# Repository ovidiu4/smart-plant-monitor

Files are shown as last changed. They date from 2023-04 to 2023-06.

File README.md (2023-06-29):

# ESP32 Powered Smart Plant Monitor

**Hello. This project is ongoing, therefore changes will be frequent.**

**Please feel free to use any part of my work for your personal projects only.**

**For commercial use please contact me!**

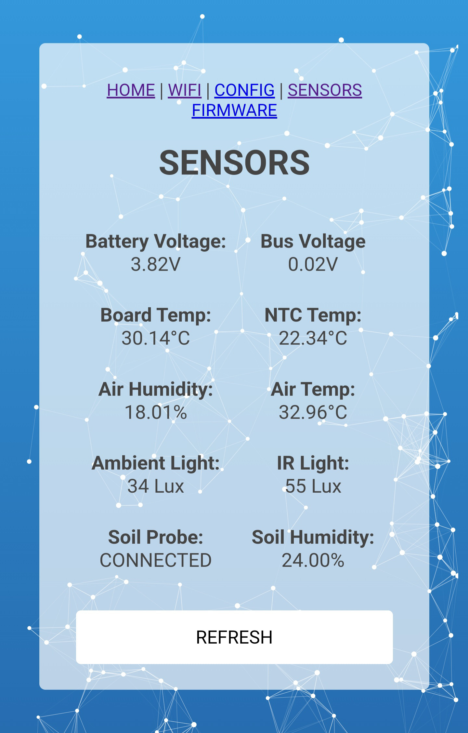
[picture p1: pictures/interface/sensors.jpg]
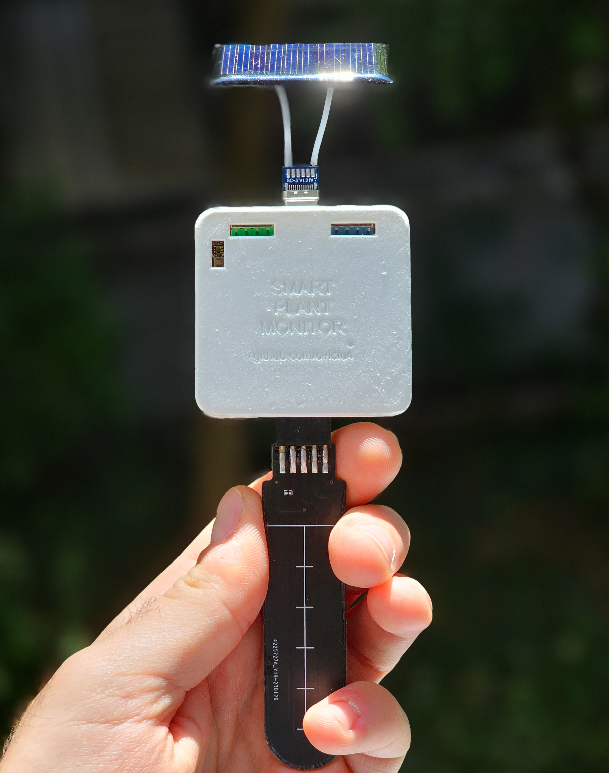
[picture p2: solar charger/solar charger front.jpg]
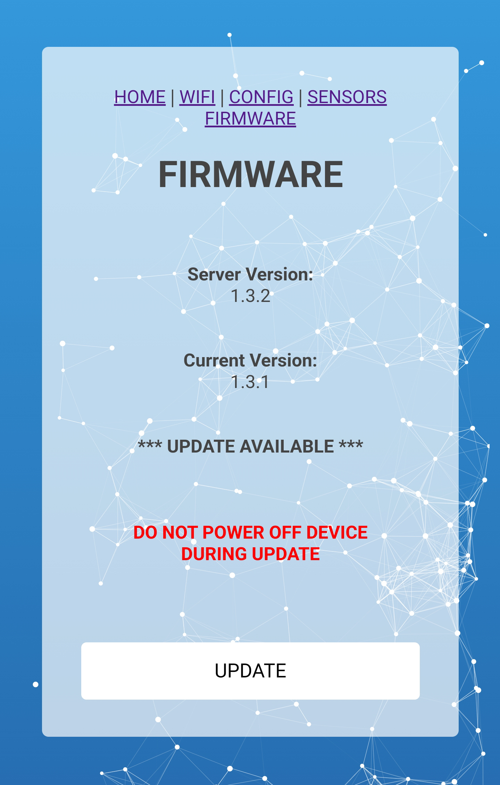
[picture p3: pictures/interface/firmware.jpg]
    

Overall features:
- Low power and small size (45x45x10mm)
- Rechargeable and programable with Arduino
- By adding a USB port to a small solar panel you've created a simple add-on 
- Can communicate via WIFI or Bluetooth
- One device can stay plugged in all the time (act as hub) while the others send updates to it (low power mode)

Back of the main board. Features:
- ESP32-S3 supports capacitance measuring directly, through the touchpad circuitry
- TP4056 charging + protection circuit
- USB C with 5.1K resistors added
- 3.3V LDO for powering everything
- Circuitry for a 1.54" E-Paper display (goes on the back)
- AHT20 IC for local air humidity and temperature measurement
- Card edge connector for easy and cheap "soil probe" PCB swap
- 2 GPIO buttons (one connected to GPIO0) and 1 status LED

Front of the main board. Features:
- Battery on-off switch
- I2C header for possible module addition
- E-Paper display
- Slim LiPo battery goes under the display. Could fit up to 4x40x30mm (usually 450-500mAh)

Soil probe. Features:
- No components and connectors added, just the bare PCB
- Cheap and easy to replace when they eventually breakdown in the soil
- Solder pads avaialble if you'd like to add a 0603 component (LED or Thermistor for soil surface temperature). Connected to GPIO through a 2K resistor
- Can be in any size and shape you'd like as long as the top matches the conector (calibration and adjustments are done in software)

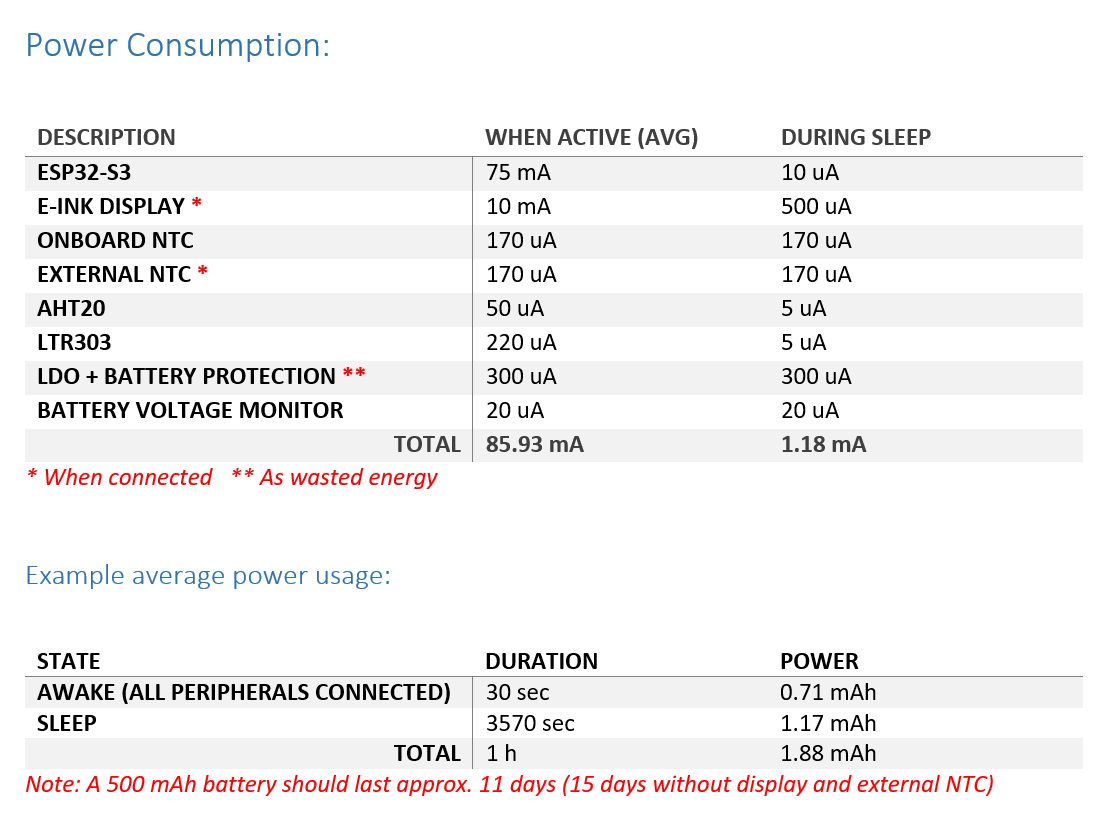
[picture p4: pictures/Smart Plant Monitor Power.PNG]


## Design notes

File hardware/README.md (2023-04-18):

If you'd like to order your own, please feel free to use the fabrication files attached here!

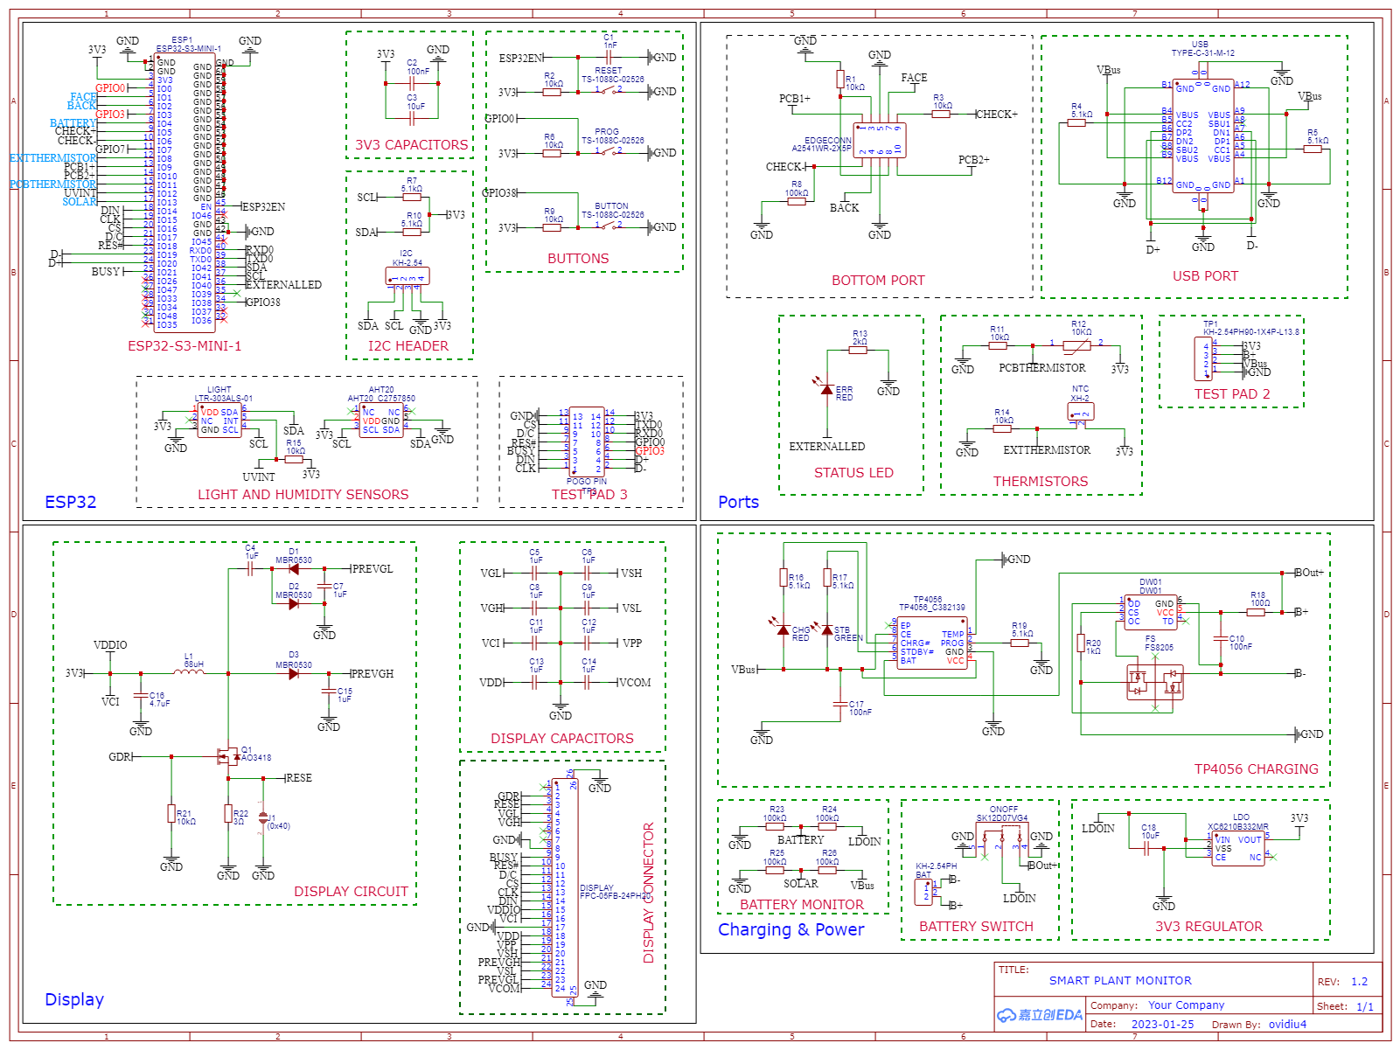
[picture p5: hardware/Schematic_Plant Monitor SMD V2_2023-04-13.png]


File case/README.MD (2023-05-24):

**STL Files for a case that perfectly fits the Smart Plant Monitor**

  


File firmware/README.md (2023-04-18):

This folder is used for the automatic updates of the board.
There is no need to download anything from here

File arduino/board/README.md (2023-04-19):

**In order to program the board yourself via Arduino IDE you need to create a custom board**

1. Add the contens of boards.txt to your boards file on your computer. It is typically located at:
   "C:\Users\\\*USER*\AppData\Local\Arduino15\packages\esp32\hardware\esp32\2.0.7\boards.txt"

2. Copy the entire folder "ovidiu4_esp32s3" to the variants folder on your computer. It is typically located at:
   "C:\Users\\\*USER*\AppData\Local\Arduino15\packages\esp32\hardware\esp32\2.0.7\variants\"
   
3. Restart Arduino and select the custom board "Ovidiu4 Smart Plant Monitor ESP32-S3"

4. Adjust the following settings:

   a. USB Mode: Hardware CDC and JTAG

   b. CPU Frequency: 80MHz

   c. Partition Scheme: Default 4MB with SPIFFS

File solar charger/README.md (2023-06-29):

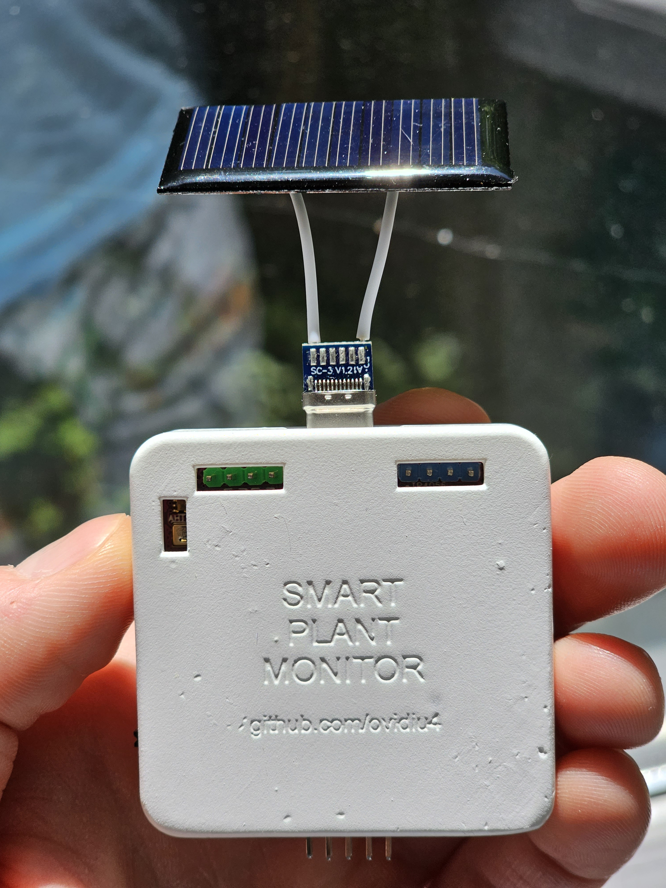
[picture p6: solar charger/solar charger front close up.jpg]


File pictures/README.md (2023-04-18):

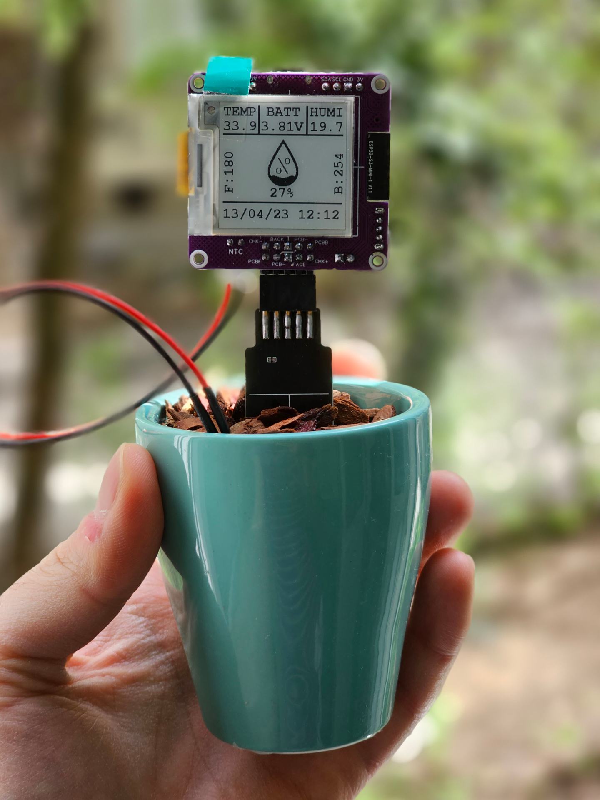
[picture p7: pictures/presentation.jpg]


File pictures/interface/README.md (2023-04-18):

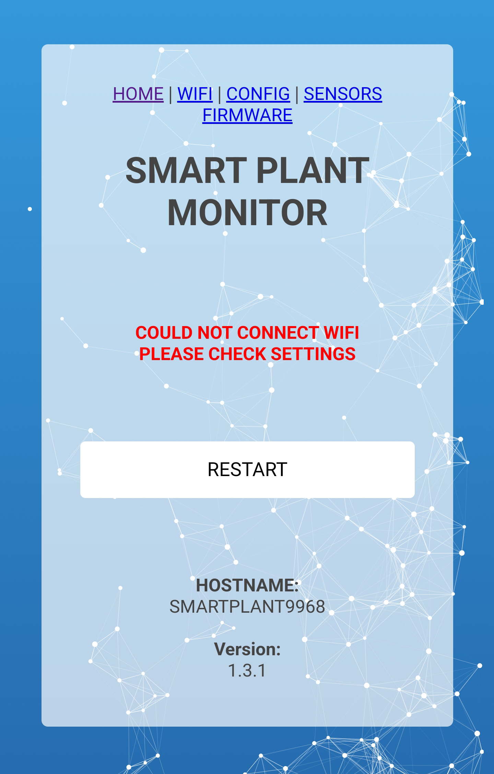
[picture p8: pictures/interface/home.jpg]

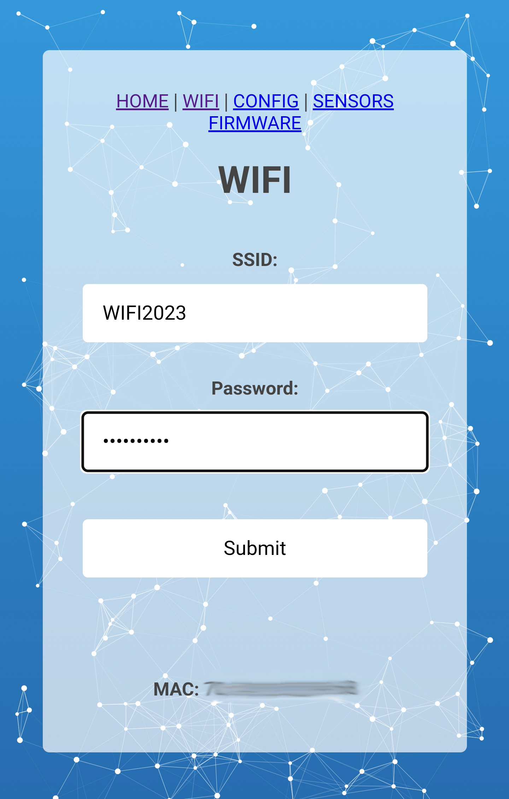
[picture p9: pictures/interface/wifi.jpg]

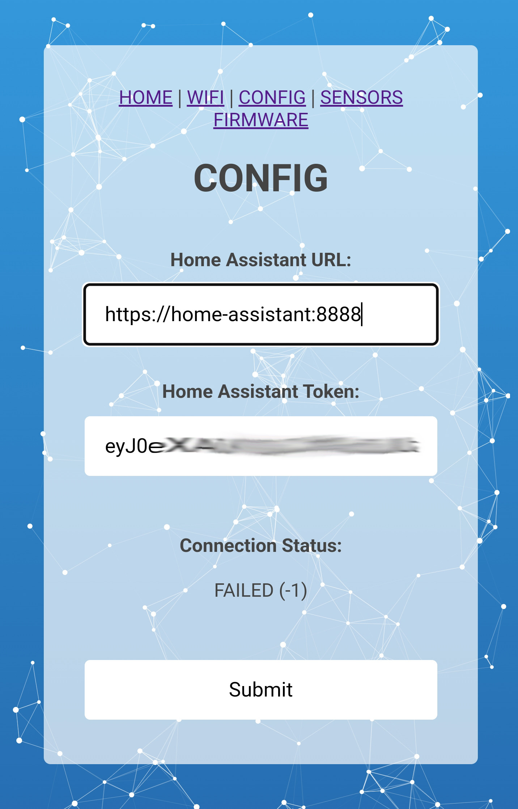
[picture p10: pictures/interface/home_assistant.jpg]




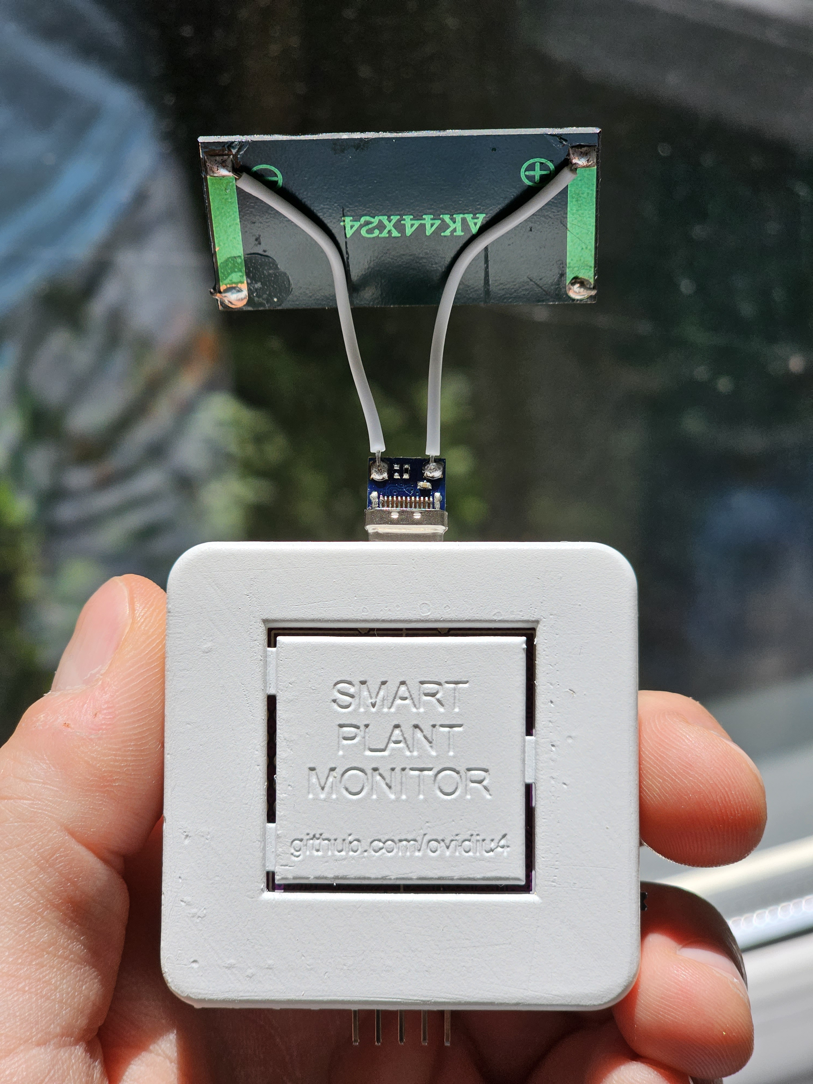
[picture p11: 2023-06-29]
solar charger/solar charger back close up.jpg

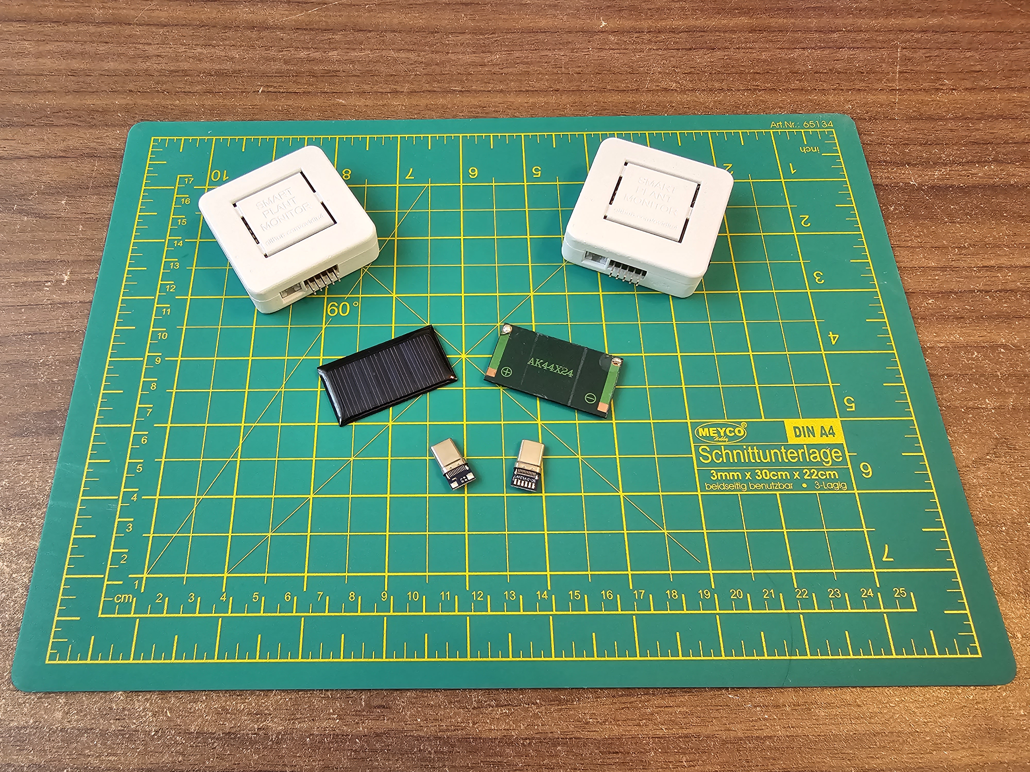
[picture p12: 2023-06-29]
solar charger/mini solar panel and usb connector.jpg

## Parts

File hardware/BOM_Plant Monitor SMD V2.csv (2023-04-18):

ID | Name | Designator | Footprint | Quantity | Manufacturer Part | Manufacturer | Supplier | Supplier Part | Price
1 | AHT20_C2757850 | AHT20 | SENSOR-SMD_L3.0-W3.0-P1.00-BR | 1 | AHT20 | 广州奥松 | LCSC | C2757850 | 0.117
2 | 1nF | C1 | C0603 | 1 | CL10B102KB8NNNC | SAMSUNG(三星) | LCSC | C1588 | 0.001
3 | 100nF | C2,C10,C17 | C0603 | 3 | CC0603KRX7R9BB104 | YAGEO(国巨) | LCSC | C14663
4 | 10uF | C3,C18 | C0603 | 2 | CL10A106KP8NNNC | SAMSUNG(三星) | LCSC | C19702 | 0.001
5 | 1uF | C4,C5,C6,C7,C8,C9,C11,C12,C13,C14,C15 | C0603 | 11 | CL10A105KB8NNNC | SAMSUNG(三星) | LCSC | C15849 | 0.001
6 | 4.7uF | C16 | C0603 | 1 | CL10A475KO8NNNC | SAMSUNG(三星) | LCSC | C19666 | 0.002
7 | RED | CHG,ERR | LED0603-R-RD | 2 | KT-0603R | KENTO | LCSC | C2286
8 | MBR0530 | D1,D2,D3 | SOD-123_L2.8-W1.8-LS3.7-RD | 3 | MBR0530 | CJ(江苏长电/长晶) | LCSC | C77336 | 0.005
9 | FPC-05FB-24PH20 | DISPLAY | FPC-SMD_24P-P0.50_FPC-05FB-24PH20 | 1 | FPC-05FB-24PH20 | XUNPU(讯普) | LCSC | C2856831 | 0.023
10 | DW01 | DW01 | SOT-23-6_L2.9-W1.6-P0.95-LS2.8-BR | 1 | DW01 | Hottech(合科泰) | LCSC | C181096 | 0.006
11 | ESP32-S3-MINI-1 | ESP1 | BULETM-SMD_ESP32-S3-MINI-1-N8 | 1 | ESP32-S3-MINI-1 | null | LCSC | C9900015247
12 | FS8205 | FS | SOT-23-6_L2.9-W1.6-P0.95-LS2.8-BR | 1 | FS8205 | FORTUNE(富晶) | LCSC | C32254 | 0.031
13 | (0x40) | J1 | JUMPER2-0603_NC | 1 | ?
14 | 68uH | L1 | L1210 | 1 | CMI322513J680MT | FH(风华) | LCSC | C401470 | 0.015
15 | XC6210B332MR | LDO | TSOT-23-5_L2.9-W1.6-P0.95-LS2.8-BR | 1 | XC6210B332MR | TOREX(特瑞仕) | LCSC | C424705 | 0.056
16 | LTR-303ALS-01 | LIGHT | SOT-363_L2.0-W1.3-P0.65-LS2.1-BL | 1 | LTR-303ALS-01 | LITEON(光宝) | LCSC | C364577 | 0.063
17 | AO3418 | Q1 | SOT-23-3_L2.9-W1.3-P1.90-LS2.4-BR | 1 | AO3418 | AOS | LCSC | C21713 | 0.015
18 | 10kΩ | R1,R2,R3,R6,R9,R11,R14,R15,R21 | R0603 | 9 | 0603WAF1002T5E | UNI-ROYAL(厚声) | LCSC | C25804
19 | 5.1kΩ | R4,R5,R7,R10,R16,R17,R19 | R0603 | 7 | 0603WAF5101T5E | UNI-ROYAL(厚声) | LCSC | C23186
20 | 100kΩ | R8,R23,R24,R25,R26 | R0603 | 5 | 0603WAF1003T5E | UNI-ROYAL(厚声) | LCSC | C25803
21 | 10KΩ | R12 | R0603 | 1 | NTCS0603E3103FLT | VISHAY(威世) | LCSC | C142556 | 0.112
22 | 2kΩ | R13 | R0603 | 1 | 0603WAF2001T5E | UNI-ROYAL(厚声) | LCSC | C22975
23 | 100Ω | R18 | R0603 | 1 | 0603WAF1000T5E | UNI-ROYAL(厚声) | LCSC | C22775
24 | 1kΩ | R20 | R0603 | 1 | 0603WAF1001T5E | UNI-ROYAL(厚声) | LCSC | C21190
25 | 3Ω | R22 | R0603 | 1 | 0603WAF300KT5E | UNI-ROYAL(厚声) | LCSC | C23157
26 | GREEN | STB | LED0603-R-RD | 1 | 19-217/GHC-YR1S2/3T | EVERLIGHT | LCSC | C72043 | 0.004
27 | TP4056_C382139 | TP4056 | ESOP-8_L4.9-W3.9-P1.27-LS6.0-BL-EP | 1 | TP4056 | TPOWER | LCSC | C382139 | 0.019
28 | TYPE-C-31-M-12 | USB | USB-C_SMD-TYPE-C-31-M-12 | 1 | TYPE-C-31-M-12 | Rectangular Connectors - Contacts | LCSC | C165948 | 0.035

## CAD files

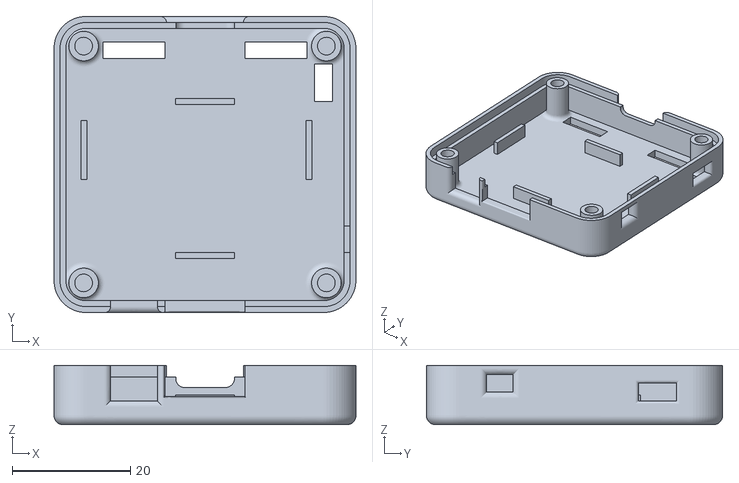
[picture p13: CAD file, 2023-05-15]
case/Case Bottom.stl
51.0 x 50.0 x 10.00

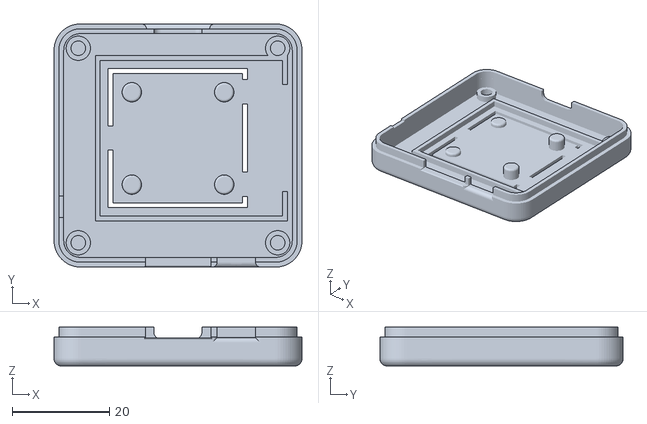
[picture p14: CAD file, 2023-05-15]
case/Case Top.stl
51.0 x 50.0 x 8.00

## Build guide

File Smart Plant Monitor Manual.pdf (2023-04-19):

# Smart Plant Monitor

Based on the ESP32-S3-MINI-1

## Board Overview:

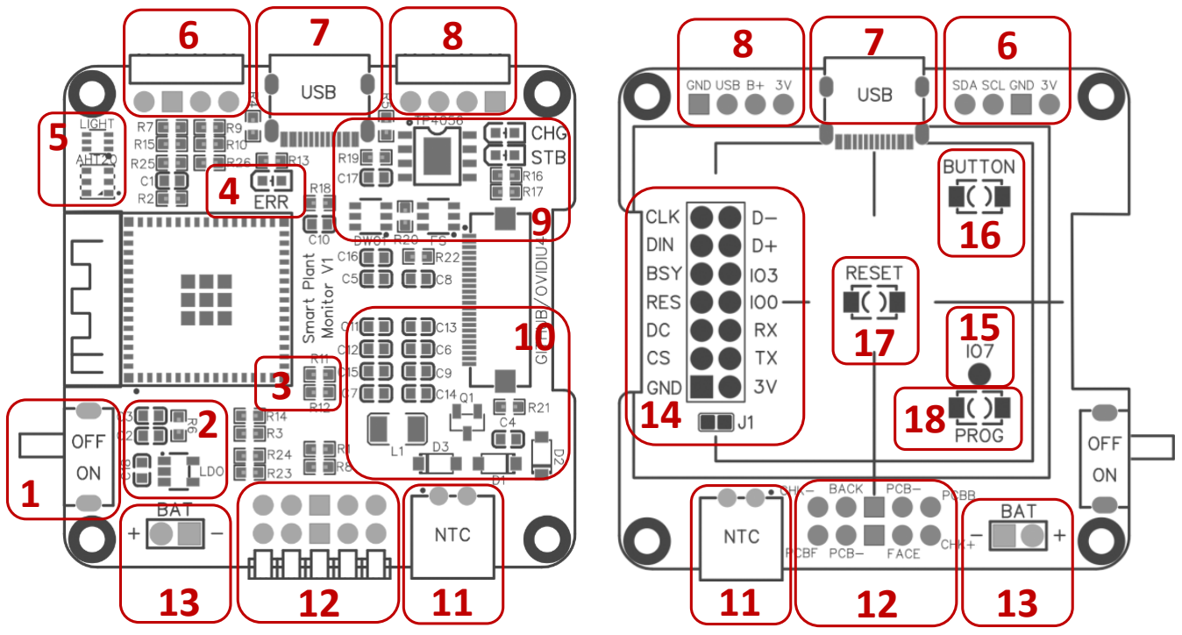
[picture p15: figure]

1. ON/OFF Switch: Connects the LDO (2) to the battery charge/protection (9) circuit.
2. 3.3V LDO: Powers all components and sensors
3. Board Thermistor: This thermistor is used to measure the board temperature. If a battery is installed over it, it can detect overheating
4. “ERR” LED: This LED is used as a status LED to signal different states of the device (Booting, firmware updating, etc.)
5. Air and Light sensors: Will measure air humidity and temperature, ambient and IR light. The light sensor can wake up the processor when certain threshold in Lux is met (Detect day time, etc.)
6. I2C Header: Can be used to connect external devices (Relays, etc.)
7. USB Port: Can be used to charge the battery and to program the ESP32-S3
8. Voltage test pins: Can be used to measure/calibrate the different voltage levels of the board. Can also be used to inject voltage (Connect the USB pin to a 6V solar panel, connect the B+ pin to an external Li-Po battery instead of the internal one (13), etc.
9. Li-Po Charge and protection circuit: Offers various protection features:
a. 400 mA max charging / discharging current
b. Short circuit protection

c. Over charge protection
d. Over discharge protection
10. E-Ink display power circuit
11. NTC connector: Used to attach an external 10K NTC thermistor (Can be used to monitor soil temperature, etc.)
12. Soil probe connector
13. Internal Li-Po battery connector
14. Test pads: Wires can be soldered directly to the test pads and they can be reconfigured in software for your personal use
15. IO7: Connected directly to GPIO7 of the ESP32-S3. Please add a current limiting resistor (max 40mA) to avoid burning of the processor
16. Button: Hold down for 5 sec at startup to change boot mode to config mode. Hold for 10 sec to factory reset the device
17. Reset: Can be shorted to reset the device (Pulls the EN pin low)
18. Prog: Hold down at startup to enter programming mode. Used when programming via USB using Arduino IDE or other software

## Board Pinout:

Please see below the default pinout for the device with the corresponding GPIO connections.

For more details please check the schematic

Smart Plant Monitor Pin | ESP32-S3-MINI-1 Pin | Remarks
“Prog” button (18) | GPIO0 | Input. Pulled low via 10K resistor
“Face” (12) | GPIO1 | Input. No resistor
“Back” (12) | GPIO2 | Input. No resistor
“IO3 “ (14) | GPIO3 | No resistor
Battery Voltage | GPIO4 | Input. R23-R24 voltage divider
“CHK+” (12) | GPIO5 | Output. 10K resistor in series
“CHK-” (12) | GPIO6 | Input. Pulled low via 100K resistor
“IO7 “ (15) | GPIO7 | No resistor
External Thermistor (11) | GPIO8 | Input. Pulled low via 10K resistor
“PCBF” (12) | GPIO9 | No resistor
“PCBB” (12) | GPIO10 | No resistor
“PCB-“ (12) | GND | 10K resistor in series
PCB Thermistor (3) | GPIO11 | Input. Pulled low via 10K resistor
Light Interrupt | GPIO12 | Input. Pulled high via 10K resistor
VBUS Voltage | GPIO13 | Input. R25-R26 voltage divider
“DIN” (14) | GPIO14 | SPI MOSI
“CLK” (14) | GPIO15 | SPI CLK
“CS” (14) | GPIO16 | SPI CS
“DC” (14) | GPIO17 | SPI D/C
“RES” (14) | GPIO18 | SPI RES
USB D- | GPIO19
USB D+ | GPIO20
“BSY” (14) | GPIO21 | SPI Busy
“BUTTON” (16) | GPIO38 | Input. Pulled low via 10K resistor
“ERR” LED (4) | GPIO40
SCL (6) | GPIO41 | I2C SCL. Pulled high via 5.1K resistor
SDA (6) | GPIO42 | I2C SDA. Pulled high via 5.1K resistor
“RX” (14) | RXD0 | No resistor
“TX” (14) | TXD0 | No resistor

Note: Some of the test pads do not have series resistors attached. To avoid damaging the ESP32 please consider adding current limiting resistors if you intend to use the pins for other purposes

## First time setup:

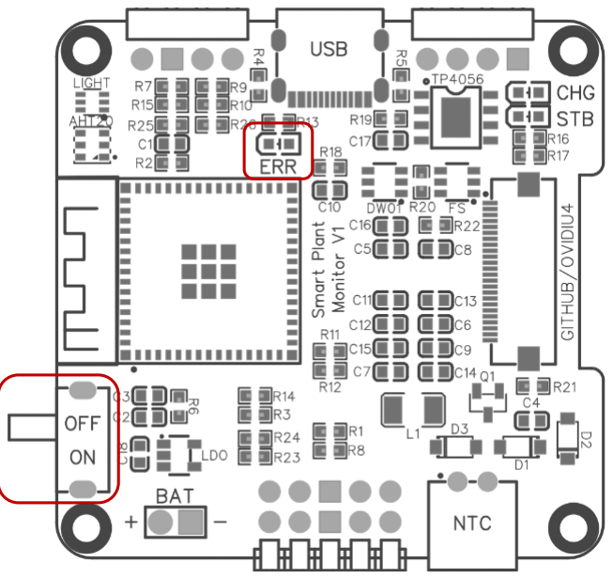
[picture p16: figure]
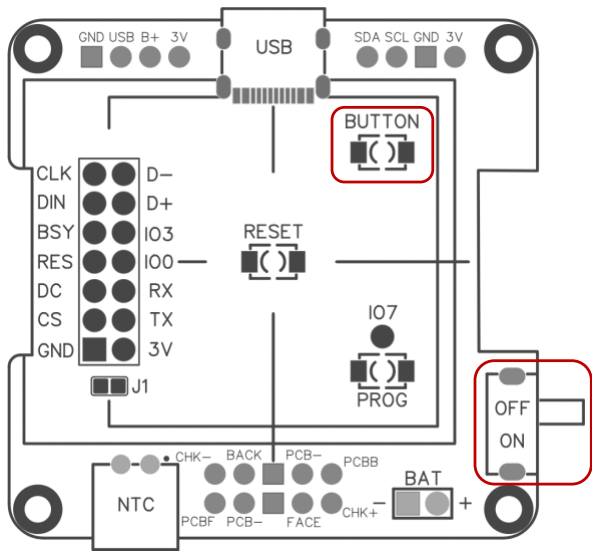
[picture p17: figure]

1. Press and hold the top button (marked with “BUTTON”)
2. Flip the power switch to “ON”
3. Wait for 5 seconds
4. The “ERR” LED will blink rapidly 3 times to signify that the “Setup Mode” is active.

Note: Holding the top button for 10 seconds will factory reset the device

5. Release the top button
6. From your smartphone or computer search for and connect to the device WIFI.
The network name will always be like “SMARTPLANTXXXX” where the last 4 characters are the device ID. Keep this name in mind.
The network password is “SMARTPLANT”

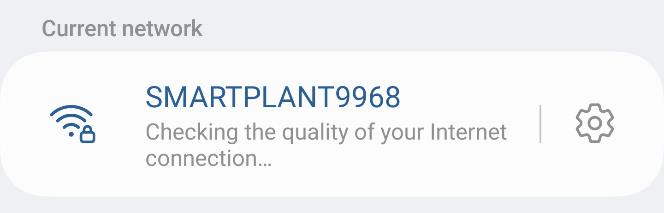
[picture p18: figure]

7. Open your browser and navigate to http://smartplantxxxx.local, replacing the last 4 characters with the ID of the device from the previous step.
Alternatively, you can navigate to http://192.168.4.1
8. Navigate to the “WIFI” page
9. Enter your WIFI SSID and Password and press “Submit”

10. Navigate to the “HOME” page and press “Restart”
11. Press and hold the top button (marked with “BUTTON”)
12. Wait for 5 seconds
13. Release the top button
14. The “ERR” LED will blink rapidly 3 times to signify that the “Setup Mode” is active.
15. Go to your Home Assistant interface and click on your name from the side menu
16. Scroll down to “Long-Lived Access Tokens”
17. Generate a new token, giving it a name that will help you remember what it is for
18. Copy this token somewhere safe
19. Open your browser and navigate to http://smartplantxxxx.local, replacing the last 4 characters with the ID of the device from the previous step.
Alternatively, you can navigate to the IP address you obtain from your Router
20. Navigate to the “CONFIG HA” page
21. Enter your Home Assistant URL (including port).
This can be an external URL or a NabuCasa URL. Do not add any trailing slashes “/”
22. Enter the Home Assistant token you generated earlier
23. Press “Submit” and confirm a connection code of “200” or “201” is returned
Alternatively you can go to home assistant and search for a new entity called “SMARTPLANTXXXX_TEST”. A random number is sent to this entity upon testing the connection.
24. Flip the power switch to “OFF”
25. Flip the power switch to “ON”
26. The device is fully configured and will now create and update multiple entities, one for each of the sensors it monitors

## Updating the Firmware:

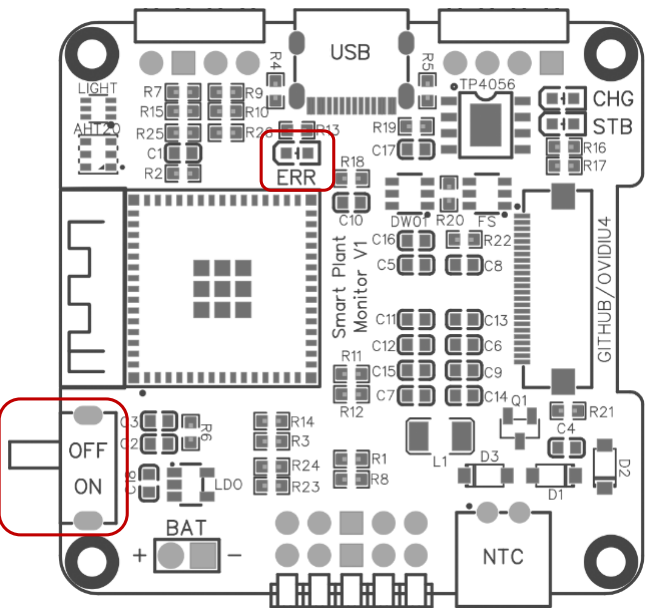
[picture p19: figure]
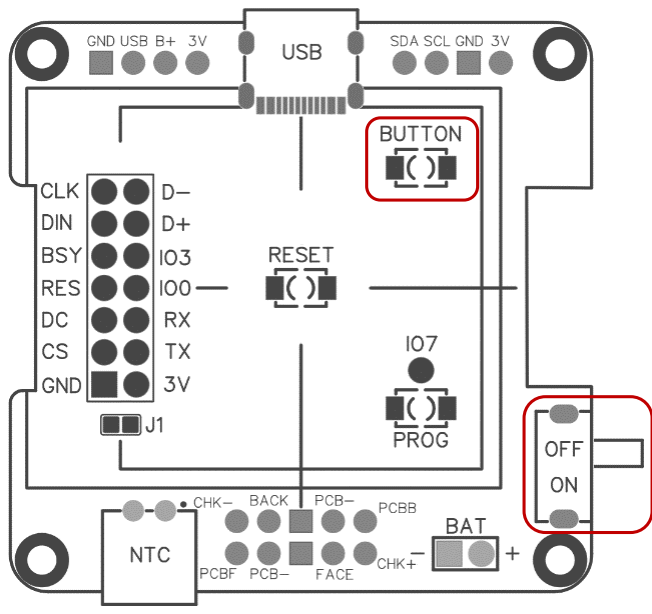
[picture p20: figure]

1. Press and hold the top button (marked with “BUTTON”)
2. Flip the power switch to “ON”
3. Wait for 5 seconds
4. The “ERR” LED will blink rapidly 3 times to signify that the “Setup Mode” is active.

Note: Holding the top button for 10 seconds will factory reset the device

5. Release the top button
6. Open your browser and navigate to http://smartplantxxxx.local, replacing the last 4 characters with the ID of the device from the previous step.
Alternatively, you can navigate to the IP address you obtain from your Router
7. Navigate to the “FIRMWARE” page
8. If there are any updates available for your device the “Update” button will be available
If there are no updates or if there is a connection issue, the “Update” button will be replaced by a “Refresh” button
9. Press the “Update” button
Your device will now check that all files required for the update are available on GitHub
The device will then download the required files and start the update

Note: Do not power off the device during the firmware update. The update is finished when the “ERR” LED is turned off and stays off. The device will automatically restart after the update

10. Confirm that the update was successful either by booting in the “Setup Mode” and navigating to the “FIRMWARE” page or by checking the value of the “Software Version” entity in your Home Assistant instance

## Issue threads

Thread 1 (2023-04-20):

[Question] I was wondering how accurate is the battery SoC tracking with voltage measurement technique.

Nickobellic15X, 2023-04-20:
Because we know that the battery voltage drops drastically when under load, so a full charge battery tested under open circuit condition may show anywhere between 4 and 4.2v but as soon as you connect it to a circuit, it will drop to 3.8V or so...

Are you compensating this in code?

ovidiu4, 2023-04-20:
To be honest I don't think that's necessary for this device.
It is only measuring the voltage under load which is what matters.
Otherwise, due to voltage drop like you said, when the battery is close to 3.4V with no load, it might cause a processor brownout when booting

Closed 2023-04-20.

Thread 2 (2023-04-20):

PCB thermistor wasting power

ovidiu4, 2023-04-20:
The onboard thermistor **(R12)** + 10K resistor **(R11)** are always connected between GND and 3.3V
This is wasting approx 0.2 mA, even during deepsleep.

The only fix is to desolder them from the PCB.

Similarily the external thermistor (**NTC port**), when connected, is wasting 0.2 mA

ovidiu4, 2023-04-20:
In a future version the 3.3V will be provided via GPIO pins, so that they can be pulled low when not in use

nglessner, 2023-04-20:
I would consider using 1 or 2 MΩ to drop that current usage since it's
always on.

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

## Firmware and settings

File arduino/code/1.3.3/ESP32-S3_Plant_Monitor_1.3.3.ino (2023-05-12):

/*
  Hello from Ovidiu
  https://github.com/ovidiu4/smart-plant-monitor
*/

#include "images.h"
#include <GxEPD.h>
//#include <GxGDEH0154D67/GxGDEH0154D67.h>  // 1.54" b/w
#include <GxGDEH0154Z90/GxGDEH0154Z90.h>  // 1.54" b/w/r 200x200 SSD1681
#include <GxIO/GxIO_SPI/GxIO_SPI.h>
#include <GxIO/GxIO.h>
#include <Fonts/FreeMonoBold9pt7b.h>
#include <Fonts/FreeMonoBold12pt7b.h>

#include <WiFi.h>
#include <AsyncTCP.h>
#include <ESPAsyncWebServer.h>
#include <HTTPClient.h>
#include <ESPmDNS.h>
#include <ESP32httpUpdate.h>
#include <NTPClient.h>
#include <WiFiUdp.h>
#include <ESP32Time.h>
#include "SPIFFS.h"
#include "EEPROM.h"
#include <Adafruit_AHTX0.h>
#include "Adafruit_LTR329_LTR303.h"
#include "driver/periph_ctrl.h"
#include <Arduino_JSON.h>

// ---------- PINS ---------- //
#define wakeup_pin             GPIO_NUM_0
#define face_pin               1
#define back_pin               2

//#define GPIO3                3 //DO NOT CHANGE! DO NOT USE!

#define batteryPin             4
#define check_pin_out          5
#define check_pin_in           6

//#define GPIO7                7 // CAN BE USED. Pad connected directly to Pin. Keep in mind that a current limiting resistor may be needed

#define ThermistorPin          8
#define face_led_pin           9
#define back_led_pin           10
#define PCBThermistorPin       11
#define IRint                  12
#define usbPin                 13

#define MOSI                   14 //DO NOT CHANGE!
#define SCK                    15 //DO NOT CHANGE!

#define SS                     16 //DO NOT CHANGE!
#define CS_Pin                 16
#define DC_Pin                 17
#define RES_Pin                18

//#define D-                   19 //DO NOT CHANGE!
//#define D+                   20 //DO NOT CHANGE!

#define BUSY_Pin               21

#define MISO                   37 //DO NOT CHANGE!
#define button_pin             38
#define external_led_pin       40

#define SCL                    41 //DO NOT CHANGE!
#define SDA                    42 //DO NOT CHANGE!
// ---------- PINS ---------- //


// ---------- THERMISTOR ---------- //
float Vo;
float R1 = 10000; // value of R1 on board
float logR2, R2, T;
float c1 = 0.001129148, c2 = 0.000234125, c3 = 0.0000000876741; 
// ---------- THERMISTOR ---------- //

// ---------- VERSION ---------- //
String own_version="1.3.3b";
String server_version="N/A";
int update_code = 0;
int firmware_code = 0;
bool perform_update = false;
const char* version_file = "https://raw.githubusercontent.com/ovidiu4/smart-plant-monitor/main/firmware/version.txt";
const char* firmware_file = "https://raw.githubusercontent.com/ovidiu4/smart-plant-monitor/main/firmware/firmware.bin";
const char* tree_file = "https://raw.githubusercontent.com/ovidiu4/smart-plant-monitor/main/firmware/data/tree.txt";
String github_data_path = "https://raw.githubusercontent.com/ovidiu4/smart-plant-monitor/main/firmware/data/";
// ---------- VERSION ---------- //

// ---------- WIFI ---------- //
char* ssid = (char*)malloc(64);
char* password = (char*)malloc(64);
bool wifi_status = false;
IPAddress local_ip(192,168,4,1);
IPAddress gateway(192,168,4,1);
IPAddress subnet(255,255,255,0);
String hostname = "SMARTPLANT" + String(random(99)); //Initial value. Should be updated later in the code
String wifi_networks = "<option value=\"SCANNING\">SCANNING</option>"; //Initial value. Should be updated later in the code
// ---------- WIFI ---------- //

// ---------- EEPROM ---------- //
#define EEPROM_SIZE            656 //SSID=64, PASS=64, APIKEY=256, URL=256, Interval = 16
String eeprom_ssid = "";
String eeprom_password = "";
String eeprom_apiKey = ""; 
String eeprom_home_assistant_url = ""; 
String eeprom_update_interval = "";
// ---------- EEPROM ---------- //


// ---------- SENSORS ---------- //
float soil_humidity_max = 800; 
float soil_humidity_min = 0; 
float soil_face_value = 0;
float soil_back_value = 0;
float soil_measurement_average = 0;
float soil_humidity = 0;
float soil_humidity_percent = 0; 
float soil_temperature = 0;
float battery_voltage = 0;
int battery_percent = 0;
float bus_voltage = 0;
float board_temperature = 0;
float air_temperature = 0;
float air_humidity = 0;
uint16_t ambient_light = 0;
uint16_t ir_light = 0;
bool valid;
// ---------- SENSORS ---------- //

// ---------- TIMEOUTS ---------- //
float deep_sleep_time = 1800e6; //Measured in uS
int wifi_timeout = 10000; //Measured in mS
int http_timeout = 10000; //Measured in mS
unsigned long loop_time = 0;
int boot_mode_delay = 3000;
int reset_delay = 10000;
// ---------- TIMEOUTS ---------- //


// ---------- TIME ---------- //
const long utcOffsetInSeconds = 10800;
unsigned long rtcOffset = 0;
unsigned long seconds = 0;
unsigned long minutes = 0;
unsigned long hours = 0;
unsigned long days = 0;
char daysOfTheWeek[7][12] = {"Sunday", "Monday", "Tuesday", "Wednesday", "Thursday", "Friday", "Saturday"};
WiFiUDP ntpUDP;
NTPClient timeClient(ntpUDP, "pool.ntp.org", utcOffsetInSeconds);
// ---------- TIME ---------- //

// ---------- HOMEASSISTANT ---------- //
const char* plant_monitor_air_temperature = "_air_temperature";
const char* plant_monitor_air_humidity = "_air_humidity";
const char* plant_monitor_battery_percent = "_battery_percent";
const char* plant_monitor_battery_voltage = "_battery_voltage";
const char* plant_monitor_board_temperature = "_board_temperature";
const char* plant_monitor_bus_voltage = "_bus_voltage";
const char* plant_monitor_soil_moisture_face = "_soil_moisture_face";
const char* plant_monitor_soil_moisture_back = "_soil_moisture_back";
const char* plant_monitor_soil_moisture_percent = "_soil_moisture_percent";
const char* plant_monitor_soil_temperature = "_monitor_soil_temperature";
const char* plant_monitor_ambient_light = "_ambient_light";
const char* plant_monitor_ir_light = "_ir_light";
const char* plant_monitor_version = "_firmware_version";
const char* plant_monitor_update_interval = "_update_interval";
int test_connection_code ;
String apiKey = ""; 
String home_assistant_url = ""; 
float home_assistant_deep_sleep_time = 0;
// ---------- HOMEASSISTANT ---------- //

// ---------- OTHER ---------- //
bool restarting = false;
bool boot_into_config = false; 
bool reset_complete = false;
bool board_check = false;
bool home_assistant_connection = false;
bool wifi_saved_eeprom = false;
bool config_saved_eeprom = false;
// ---------- OTHER ---------- //

String restart_button_value = "RESTART";
String firmware_status = "COULD NOT CHECK SERVER";

ESP32Time rtc;
Adafruit_AHTX0 aht;
Adafruit_LTR303 ltr = Adafruit_LTR303();
AsyncWebServer server(80);

GxIO_Class io(SPI, /*CS*/ CS_Pin, /*DC*/ DC_Pin, /*RST*/ RES_Pin); 
GxEPD_Class display(io, /*RST*/ RES_Pin, /*BUSY*/ BUSY_Pin); 



void setup(void)
{
  Serial.begin(115200);
  Serial.println();
  Serial.println("*** WAKING UP ***");

  pinMode(IRint, INPUT);
  pinMode(button_pin, INPUT);
  pinMode(external_led_pin, OUTPUT);
  pinMode(face_led_pin, OUTPUT);
  pinMode(back_led_pin, OUTPUT);
  pinMode(ThermistorPin, INPUT);
  pinMode(PCBThermistorPin, INPUT);

  digitalWrite(external_led_pin, HIGH);
  delay(200);
  digitalWrite(external_led_pin, LOW);

  battery_voltage = get_battery_voltage();
  
  String mac = WiFi.macAddress();
  hostname = "SMARTPLANT" + mac.substring(mac.length()-5, mac.length()-3) + mac.substring(mac.length()-2, mac.length());
  Serial.print("Hostname: ");
  Serial.println(hostname);
  Serial.print("Version: ");
  Serial.println(own_version);
     
  Serial.print("LTR Begin: ");
  if(ltr.begin()){
    Serial.println("OK");
    ltr.setGain(LTR3XX_GAIN_1);
    ltr.setIntegrationTime(LTR3XX_INTEGTIME_50);
    ltr.setMeasurementRate(LTR3XX_MEASRATE_2000);
    ltr.enableInterrupt(false);
    ltr.setInterruptPolarity(false);
    ltr.setLowThreshold(2);
    ltr.setHighThreshold(10000);
    ltr.setIntPersistance(5);

    Serial.print("  Gain : ");
    switch (ltr.getGain()) {
      case LTR3XX_GAIN_1: Serial.println(1); break;
      case LTR3XX_GAIN_2: Serial.println(2); break;
      case LTR3XX_GAIN_4: Serial.println(4); break;
      case LTR3XX_GAIN_8: Serial.println(8); break;
      case LTR3XX_GAIN_48: Serial.println(48); break;
      case LTR3XX_GAIN_96: Serial.println(96); break;
    }
    
    Serial.print("  Integration Time (ms): ");
    switch (ltr.getIntegrationTime()) {
      case LTR3XX_INTEGTIME_50: Serial.println(50); break;
      case LTR3XX_INTEGTIME_100: Serial.println(100); break;
      case LTR3XX_INTEGTIME_150: Serial.println(150); break;
      case LTR3XX_INTEGTIME_200: Serial.println(200); break;
      case LTR3XX_INTEGTIME_250: Serial.println(250); break;
      case LTR3XX_INTEGTIME_300: Serial.println(300); break;
      case LTR3XX_INTEGTIME_350: Serial.println(350); break;
      case LTR3XX_INTEGTIME_400: Serial.println(400); break;
    }
    
    Serial.print("  Measurement Rate (ms): ");
    switch (ltr.getMeasurementRate()) {
      case LTR3XX_MEASRATE_50: Serial.println(50); break;
      case LTR3XX_MEASRATE_100: Serial.println(100); break;
      case LTR3XX_MEASRATE_200: Serial.println(200); break;
      case LTR3XX_MEASRATE_500: Serial.println(500); break;
      case LTR3XX_MEASRATE_1000: Serial.println(1000); break;
      case LTR3XX_MEASRATE_2000: Serial.println(2000); break;
    }
    
    Serial.print("  Consecutive counts for IRQ: ");  Serial.println(ltr.getIntPersistance());
    Serial.print("  Thresholds: "); Serial.print(ltr.getLowThreshold()); Serial.print(" & "); Serial.println(ltr.getHighThreshold());
  }

  
  Serial.print("AHT Begin: ");
  if(aht.begin()){
    Serial.println("OK");
  }

  Serial.print("SPIFFS Begin: ");
  if(SPIFFS.begin(true)){
    Serial.println("OK");
  }

  Serial.print("EEPROM Begin: ");
  if(EEPROM.begin(EEPROM_SIZE)) {
    Serial.println("OK");
  }

  loop_time = millis();
  
  while(digitalRead(button_pin) == 0 && reset_complete == false){
    digitalWrite(external_led_pin, HIGH);
    delay(500);
    digitalWrite(external_led_pin, LOW);
    delay(500);

    if(millis() > loop_time + boot_mode_delay && boot_into_config == false){
      digitalWrite(external_led_pin, HIGH);
      delay(100);
      digitalWrite(external_led_pin, LOW);
      delay(100);
      digitalWrite(external_led_pin, HIGH);
      delay(100);
      digitalWrite(external_led_pin, LOW);
      delay(100);
      boot_into_config = true;
    }
    if(millis() > loop_time + reset_delay){
      
      ssid = "";
      password = "";
      apiKey = ""; 
      home_assistant_url = ""; 
      eeprom_update_interval = "1800";
      
      int addr = 0;
      for (int i = 0; i < EEPROM_SIZE; i++) {
          EEPROM.write(addr, 0);
          addr += 1;
      }
      EEPROM.writeString(640, eeprom_update_interval);
      
      if(EEPROM.commit()){
        digitalWrite(external_led_pin, HIGH);
        delay(100);
        digitalWrite(external_led_pin, LOW);
        delay(100);
        digitalWrite(external_led_pin, HIGH);
        delay(100);
        digitalWrite(external_led_pin, LOW);
        delay(100);
        digitalWrite(external_led_pin, HIGH);
        delay(100);
        digitalWrite(external_led_pin, LOW);
        delay(100);
        digitalWrite(external_led_pin, HIGH);
        delay(100);
        digitalWrite(external_led_pin, LOW);
        delay(100);
        digitalWrite(external_led_pin, HIGH);
        delay(100);
        digitalWrite(external_led_pin, LOW);
        delay(100);
        reset_complete == true;
      }
    
      break;
    }
  }

  eeprom_ssid = "";
  eeprom_password = "";
  eeprom_apiKey = ""; 
  eeprom_home_assistant_url = ""; 
  eeprom_update_interval = ""; 

  Serial.println("*** READING EEPROM ***");
  
  eeprom_ssid = EEPROM.readString(0);
  Serial.print("  SSID: ");
  Serial.println(eeprom_ssid);
  eeprom_password = EEPROM.readString(64);
  Serial.print("  PASS: ");
  Serial.println(eeprom_password);
  eeprom_apiKey = EEPROM.readString(128);
  Serial.print("  API: ");
  Serial.println(eeprom_apiKey);
  eeprom_home_assistant_url = EEPROM.readString(384);
  Serial.print("  URL: ");
  Serial.println(eeprom_home_assistant_url);
  eeprom_update_interval = EEPROM.readString(640);
  Serial.print("  Update Interval: ");
  Serial.println(eeprom_update_interval);
  delay(1000);
  Serial.println("*** EEPROM READ COMPLETE***");

  
  eeprom_ssid.toCharArray(ssid, eeprom_ssid.length()+1);
  eeprom_password.toCharArray(password, eeprom_password.length()+1);
  
  apiKey = String(eeprom_apiKey);
  home_assistant_url = String(eeprom_home_assistant_url);

  deep_sleep_time = (eeprom_update_interval.toFloat()) * 1000000; //Measured in uS
  if(deep_sleep_time == 0){
    deep_sleep_time = 1800 * 1000000; //Measured in uS
  }
  
  Serial.print("  SSID: ");
  Serial.println(ssid);
  Serial.print("  PASS: ");
  Serial.println(password);
  Serial.print("  API: ");
  Serial.println(apiKey);
  Serial.print("  URL: ");
  Serial.println(home_assistant_url);
  Serial.print("  Update Interval: ");
  Serial.println(deep_sleep_time);
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
void loop()
{
  soil_face_value = touchRead(face_pin) / 1000;
  soil_back_value = touchRead(back_pin) / 1000;
  delay(100);
  soil_humidity = (soil_face_value + soil_back_value) / 2;
  soil_humidity_percent = map(soil_humidity,soil_humidity_min,soil_humidity_max,0,100);
  
  if(soil_humidity_percent < 0){
    soil_humidity_percent = 0;
  }

  if(restarting == true){
    ESP.restart();
  }
  
  
  sensors_event_t aht_humidity, aht_temperature;
  aht.getEvent(&aht_humidity, &aht_temperature);// populate temp and humidity objects with fresh data
  air_humidity = aht_humidity.relative_humidity;
  air_temperature = aht_temperature.temperature;
  
  //battery_percent = 0;
  //battery_voltage = get_battery_voltage();

  if (ltr.newDataAvailable()) {
    valid = ltr.readBothChannels(ambient_light, ir_light);
    if (valid) {

    }
  }

  battery_voltage = get_battery_voltage();
  battery_percent = get_battery_percent();
  board_temperature = get_pcb_thermistor();
  soil_temperature = get_thermistor();
  bus_voltage = get_bus_voltage();
  board_check = check_board();

  if(boot_into_config == false){

    if(wifi_status = true){
      send_data_home_assistant();
      home_assistant_deep_sleep_time = get_sleep_home_assistant();
      if(home_assistant_deep_sleep_time < 1){
       Serial.println("  ERROR Home Assistant Sleep!");
       Serial.print("  Keeping Sleep Time: ");
       Serial.println(deep_sleep_time);
      }else{
        deep_sleep_time = home_assistant_deep_sleep_time * 60000000; //From minutes to uS
        Serial.print("  Updated Home Assistant Sleep: ");
        Serial.println(deep_sleep_time);
      }
      
    }
    WiFi.disconnect(true);
    WiFi.mode(WIFI_OFF);
    
    Serial.println("*** UPDATING DISPLAY ***");
    display_update_temperature();
    display_update_battery();
    display_update_humidity();
    display_update_humidity_icon();
    display_update_light_icon();
    //display_update_capacitance();
    display_update_date_time();
    
    display.updateWindow(0, 0, 200, 200, true);

    Serial.println("*** UPDATING DISPLAY DONE***");
    
        
    esp_sleep_enable_ext0_wakeup(wakeup_pin,0);
    esp_sleep_enable_timer_wakeup(deep_sleep_time);
    
    Serial.println("*** SLEEPING ***");
    Serial.print("  See you in: ");
    Serial.print(deep_sleep_time);
    Serial.println(" uS");
    digitalWrite(external_led_pin, HIGH);
    delay(200);
    digitalWrite(external_led_pin, LOW);
    
    ltr.enable(false);
    periph_module_disable(PERIPH_I2C0_MODULE);  
    digitalWrite(SDA, 0);
    digitalWrite(SCL, 0);
    digitalWrite(IRint, 1);
    
    esp_deep_sleep_start();
  }
  
  if(firmware_code == 1 && perform_update == true && wifi_status == true){
    update_firmware();
  }
    
}

void notFound(AsyncWebServerRequest *request) {
  request->send(SPIFFS, "/index.html", String(), false, processor);
}


float get_battery_voltage(){
  float sensorValue = 0;
  for (int i = 1; i <= 50; i++) {
    sensorValue = sensorValue + analogReadMilliVolts(batteryPin);
    delay(1);
  }
  sensorValue = sensorValue/50;
  return sensorValue/475;
}

float get_bus_voltage(){
  float sensorValue = 0;
  for (int i = 1; i <= 50; i++) {
    sensorValue = sensorValue + analogReadMilliVolts(usbPin);
    delay(1);
  }
  sensorValue = sensorValue/50;
  return sensorValue/455;
}

float get_battery_percent(){
  int i = 0;
  float percentage = 0;
  float values[] = {2.55, 3.05, 3.19, 3.27, 3.31, 3.35, 3.36, 3.37, 3.39, 3.395, 3.4, 3.41, 3.42, 3.43, 3.44, 3.45, 3.46, 3.47, 3.475, 3.48, 3.485, 3.49, 3.5, 3.51, 3.513, 3.516, 3.52, 3.525, 3.53, 3.535, 3.54, 3.545, 3.55, 3.5525, 3.555, 3.5575, 3.56, 3.563, 3.566, 3.57, 3.575, 3.58, 3.585, 3.59, 3.5925, 3.595, 3.5975, 3.6, 3.605, 3.61, 3.62, 3.625, 3.63, 3.633, 3.636, 3.64, 3.65, 3.66, 3.67, 3.68, 3.685, 3.69, 3.7, 3.71, 3.72, 3.73, 3.74, 3.75, 3.76, 3.77, 3.79, 3.8, 3.81, 3.82, 3.83, 3.84, 3.85, 3.86, 3.87, 3.88, 3.885, 3.9, 3.91, 3.92, 3.93, 3.94, 3.96, 3.97, 3.98, 3.99, 4, 4.01, 4.02, 4.04, 4.05, 4.06, 4.08, 4.09, 4.11, 4.13, 4.20};
  for (i = 0; i <= sizeof(values)-1; i++) {
    if(battery_voltage >= values[i] && battery_voltage < values[i+1]){
      percentage = i + ((battery_voltage-values[i])/(values[i+1]-values[i]));
      if(percentage > 100){
        percentage = 100;
      }
      return percentage;
    }
  }
  return -1;
}

float get_thermistor(){

  float thermistorAverage = 0;
  
  for (int i=0; i<10; i++){
    Vo = analogRead(ThermistorPin);
    R2 = R1 * (4096 / Vo - 1); //calculate resistance on thermistor
    logR2 = log(R2);
    T = (1.0 / (c1 + c2*logR2 + c3*logR2*logR2*logR2)) - 273.15;
    
    thermistorAverage = thermistorAverage + T; 
    delay(2);
  }
  thermistorAverage = thermistorAverage / 10;
  return thermistorAverage;

}

float get_pcb_thermistor(){
 
  float thermistorAverage = 0;
  
  for (int i=0; i<10; i++){
    Vo = analogRead(PCBThermistorPin);
    R2 = R1 * (4096 / Vo - 1); //calculate resistance on thermistor
    logR2 = log(R2);
    T = (1.0 / (c1 + c2*logR2 + c3*logR2*logR2*logR2)) - 273.15;
    
    thermistorAverage = thermistorAverage + T; 
    delay(2);
  }
  thermistorAverage = thermistorAverage / 10;
  return thermistorAverage;
  
}


void display_update_temperature(){
  uint16_t box_x = 0;
  uint16_t box_y = 0;
  uint16_t box_w = 58;
  uint16_t box_h = 45;
  uint16_t cursor_y = box_y + 16;
  //display.fillRect(box_x, box_y, box_w, box_h, GxEPD_WHITE);
  display.setCursor(box_x, cursor_y);
  display.println("TEMP");
  display.print(air_temperature,1);
  //display.updateWindow(box_x, box_y, box_w, box_h, true);
}

void display_update_battery(){
  
  uint16_t box_x = 72;
  uint16_t box_y = 0;
  uint16_t box_w = 66;
  uint16_t box_h = 45;
  uint16_t cursor_y = box_y + 16;
  //display.fillRect(box_x, box_y, box_w, box_h, GxEPD_WHITE);
  display.setCursor(box_x, cursor_y);
  display.println("BATT");
  if(battery_voltage == 100){
    display.setCursor(box_x, cursor_y+24);
  }else{
    display.setCursor(box_x-9, cursor_y+24);
  }
  if(battery_voltage > 4.3){
    display.print("CHRG");
  }else{
    display.print(battery_voltage,2);
    display.print("V");
  }
  //display.updateWindow(box_x, box_y, box_w, box_h, true);
}

void display_update_humidity(){
  uint16_t box_x = 144;
  uint16_t box_y = 0;
  uint16_t box_w = 56;
  uint16_t box_h = 45;
  uint16_t cursor_y = box_y + 16;
  //display.fillRect(box_x, box_y, box_w, box_h, GxEPD_WHITE);
  display.setCursor(box_x, cursor_y);
  display.println("HUMI");
  display.setCursor(box_x, cursor_y+24);
  display.print(air_humidity,1);
  //display.updateWindow(box_x, box_y, box_w, box_h, true);
}

void display_update_humidity_icon(){
  uint16_t box_x = 110;
  uint16_t box_y = 54;
  uint16_t box_w = 80;
  uint16_t box_h = 80;
  uint16_t cursor_y = box_y + 16;
  
  //display.fillRect(box_x, box_y, box_w, box_h, GxEPD_WHITE);

  /*if(check_board()==false){
    display.setRotation(3);
    display.setTextColor(GxEPD_BLACK);
    display.setCursor(88, 90);
    display.print("NO");
    display.setCursor(68, 110);
    display.print("BOARD");
    display.setTextColor(GxEPD_BLACK);
  }else{*/
    display.setRotation(0);
    if(soil_humidity_percent <= 20){
      display.drawExampleBitmap(humidity_0, box_y, box_x, 80, 80, GxEPD_BLACK); //68, 60, 80, 80
    }else if(soil_humidity_percent > 20 && soil_humidity_percent <= 40){
      display.drawExampleBitmap(humidity_1, box_y, box_x, 80, 80, GxEPD_BLACK);    
    }else if(soil_humidity_percent > 40 && soil_humidity_percent <= 60){
      display.drawExampleBitmap(humidity_2, box_y, box_x, 80, 80, GxEPD_BLACK);    
    }else if(soil_humidity_percent > 60 && soil_humidity_percent <= 80){
      display.drawExampleBitmap(humidity_3, box_y, box_x, 80, 80, GxEPD_BLACK);    
    }else if(soil_humidity_percent > 80 && soil_humidity_percent <= 100){
      display.drawExampleBitmap(humidity_4, box_y, box_x, 80, 80, GxEPD_BLACK);    
    }else if(soil_humidity_percent > 100){
      display.drawExampleBitmap(humidity_5, box_y, box_x, 80, 80, GxEPD_BLACK);    
    }
  //}
  //display.updateWindow(box_x, box_y, box_w, box_h, true);
  display.setRotation(3);
  
  
  if(soil_humidity_percent < 0 | check_board()==false){
    display.setCursor(24, 150);
    display.print("ERR!");
  }else if(soil_humidity_percent >= 0 && soil_humidity_percent < 10){
    display.setCursor(40, 150);
    display.print(soil_humidity_percent,0);
    display.print("%");
  }else if(soil_humidity_percent >= 10 && soil_humidity_percent < 99){
    display.setCursor(32, 150);
    display.print(soil_humidity_percent,0);
    display.print("%");
  }else if(soil_humidity_percent >= 100){
    display.setCursor(24, 150);
    display.print(soil_humidity_percent,0);
    display.print("%");
  }
  
}
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

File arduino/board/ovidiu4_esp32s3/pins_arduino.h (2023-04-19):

#ifndef Pins_Arduino_h
#define Pins_Arduino_h

#include <stdint.h>

#define USB_VID            0x303a
#define USB_PID            0x1001
#define USB_MANUFACTURER   "Ovidiu4"
#define USB_PRODUCT        "Smart Plant Monitor ESP32-S3"
#define USB_SERIAL         "" // Empty string for MAC adddress

#define EXTERNAL_NUM_INTERRUPTS 46
#define NUM_DIGITAL_PINS        48
#define NUM_ANALOG_INPUTS       20

#define analogInputToDigitalPin(p)  (((p)<20)?(analogChannelToDigitalPin(p)):-1)
#define digitalPinToInterrupt(p)    (((p)<48)?(p):-1)
#define digitalPinHasPWM(p)         (p < 46)

#define LED_BUILTIN         13

#define I2C_POWER           7     // I2C power pin
#define PIN_I2C_POWER       7     // I2C power pin


static const uint8_t TX = 39;
static const uint8_t RX = 38;
#define TX1 TX
#define RX1 RX

static const uint8_t SDA = 42; 
static const uint8_t SCL = 41; 

static const uint8_t SS    = 16; 
static const uint8_t MOSI  = 14; 
static const uint8_t SCK   = 15; 
static const uint8_t MISO  = 37; 

static const uint8_t A0 = 18;
static const uint8_t A1 = 17;
static const uint8_t A2 = 16;
static const uint8_t A3 = 15;
static const uint8_t A4 = 14;
static const uint8_t A5 = 8;
static const uint8_t A6 = 3;
static const uint8_t A7 = 4;
static const uint8_t A8 = 5;
static const uint8_t A9 = 6;
static const uint8_t A10 = 9;
static const uint8_t A11 = 10;
static const uint8_t A12 = 11;
static const uint8_t A13 = 12;
static const uint8_t A14 = 13;

static const uint8_t T3 = 3;
static const uint8_t T4 = 4;
static const uint8_t T5 = 5;
static const uint8_t T6 = 6;
static const uint8_t T8 = 8;
static const uint8_t T9 = 9;
static const uint8_t T10 = 10;
static const uint8_t T11 = 11;
static const uint8_t T12 = 12;
static const uint8_t T13 = 13;
static const uint8_t T14 = 14;

#endif /* Pins_Arduino_h */
